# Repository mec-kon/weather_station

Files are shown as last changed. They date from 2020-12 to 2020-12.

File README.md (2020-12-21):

# weather station
A simple weather station hardware for recording temperature, humidity, pressure and airquality.
The measured data can be provided over WiFi by using an ESP8266.
This hardware is available as open source hardware and released under GPL-3.0 license.

## Description
This is a circuitboard based on an ESP8266 for reading and evaluating sensor data.
By using an ESP8266, it is possible to evaluate sensor data directly and make it available via MQTT, for example.
This makes it very easy to integrate the weather station into existing smart home systems such as OpenHAB, Home Assistant or ioBroker.
Furthermore, the ESP8266 has an efficient low power mode, which allows battery operation or operation on a solar cell.

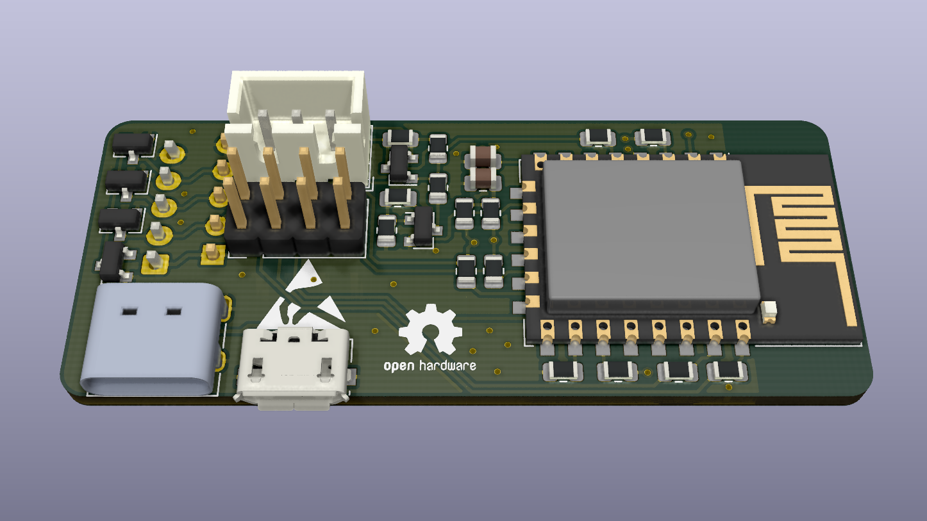
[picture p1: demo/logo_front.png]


## Connections

The board has six connection terminals.
Three different for the power supply, two for the connection of external sensors and one for programming the ESP8266. 
The power can be supplied via micro-usb, usb-c or via a JST-XH plug.
If the JST-XH connector is used, the capacity of a battery connected to the board can also be measured.

## Applicable sensors

For temperature measurement, either an LM75 and a BME680 or BME280 can be used.
If the air quality is to be measured as well, a BME680 needs to be used, otherwise a cheaper BME280 sensor is sufficient for temperature, air pressure and humidity.

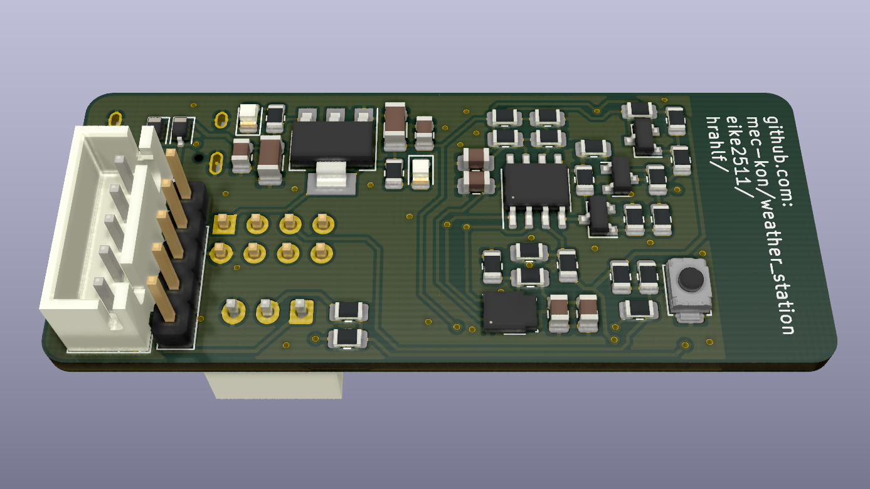
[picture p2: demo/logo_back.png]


## Low Power

To wake up the ESP8266 from low power mode, the reset pin must be connected to GPIO16. On the board presented here this connection has already been made.

## Additional external sensors

On the backside of the board a male pin header as well as a 5-pin JST-XH connector are located, to which further I2C devices or similar can be connected.

## Programming

The ESP8266 can be programmed with an FTDI adapter. All needed pins can be found on the pin header on the front side.
Example Software is provided here:

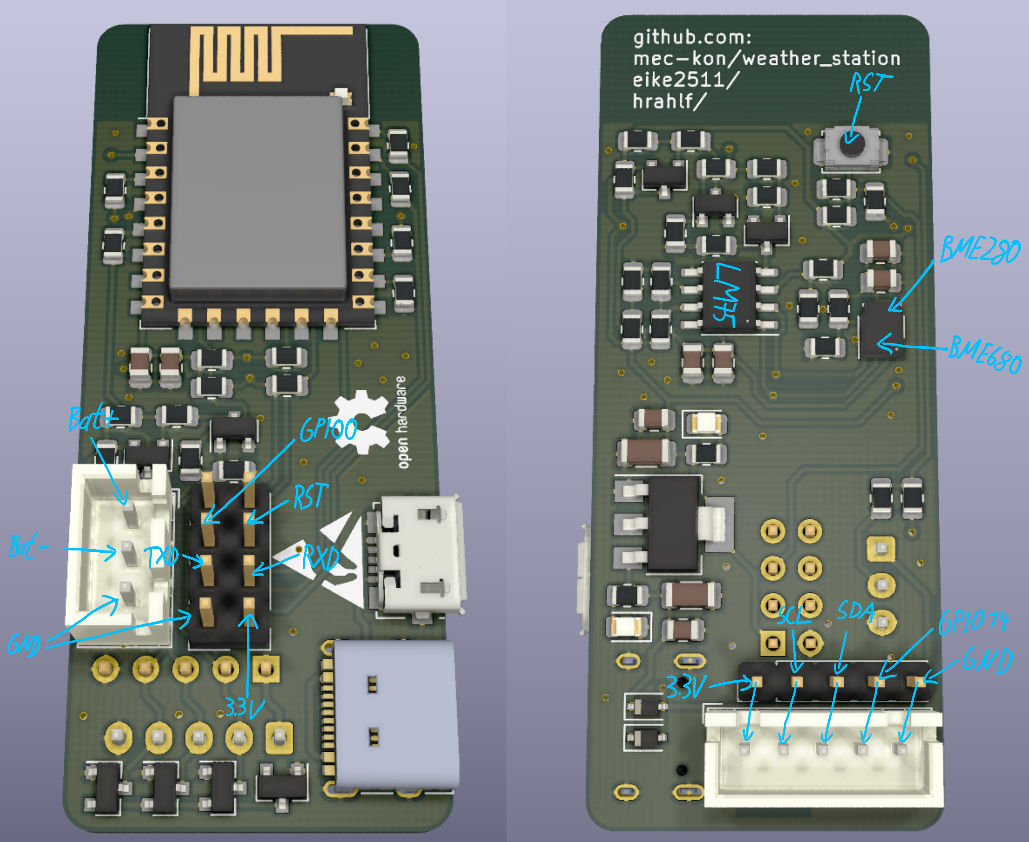
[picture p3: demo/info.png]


## Measuring the battery level

To measure the battery level, it is recommended to use a TP4056 battery charger. An additional device for charging the battery can be connected to it.
The upper pin of the JST-XH connector then corresponds to B+, the middle to B- and the lower to GND (B- and OUT- on TP4056).

## Dimensions and Schematic

24.13mmx57.8mm

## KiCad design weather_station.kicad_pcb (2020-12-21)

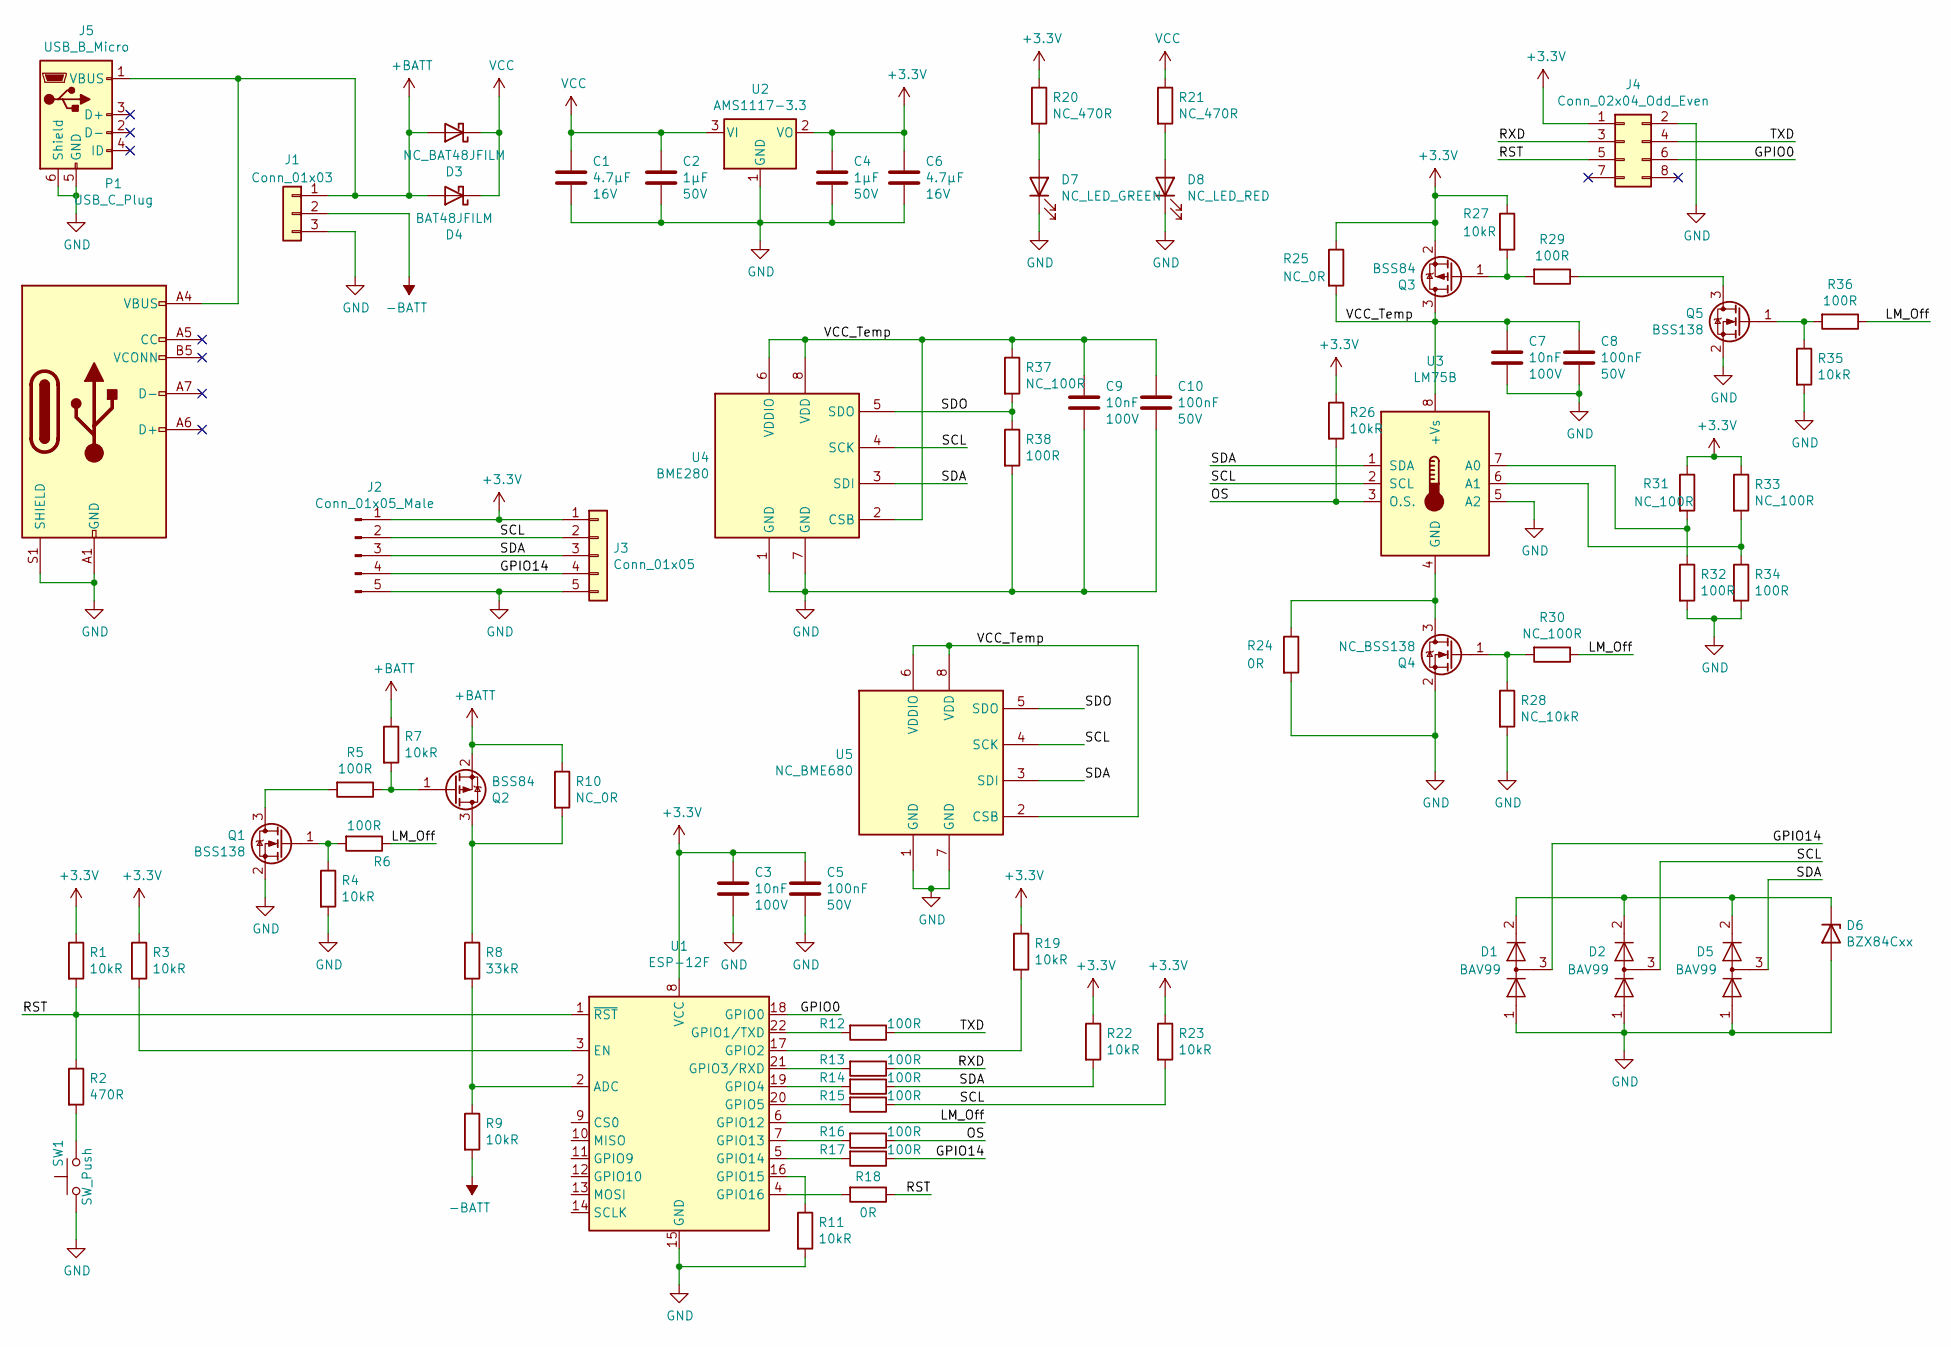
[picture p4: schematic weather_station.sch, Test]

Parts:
C1, C6: 4.7µF; C_1206_3216Metric
C2, C4: 1µF; C_0805_2012Metric
C3, C7, C9: 10nF; C_0805_2012Metric
C5, C8, C10: 100nF; C_0805_2012Metric
D1, D2, D5: BAV99; SOT-23
D3: NC_BAT48JFILM; D_SOD-323
D4: BAT48JFILM; D_SOD-323
D6: BZX84Cxx; D_SOT-23_ANK
D7: NC_LED_GREEN; LED_0805_2012Metric
D8: NC_LED_RED; LED_0805_2012Metric
J1: Conn_01x03; JST_XH_B3B-XH-A_1x03_P2.50mm_Vertical
J2: Conn_01x05_Male; PinHeader_1x05_P2.54mm_Vertical
J3: Conn_01x05; JST_XH_B5B-XH-A_1x05_P2.50mm_Vertical
J4: Conn_02x04_Odd_Even; PinHeader_2x04_P2.54mm_Vertical
J5: USB_B_Micro; USB_Micro-B_Molex_47346-0001
P1: USB_C_Plug; USB_C_Receptacle_XKB_U262-16XN-4BVC11
Q1, Q5: BSS138; SOT-23
Q2, Q3: BSS84; SOT-23
Q4: NC_BSS138; SOT-23
R1, R3, R4, R7, R9, R11, R19, R22, R23, R26, R27, R35: 10kR; R_0805_2012Metric
R2: 470R; R_0805_2012Metric
R5, R6, R12, R13, R14, R15, R16, R17, R29, R32, R34, R36, R38: 100R; R_0805_2012Metric
R8: 33kR; R_0805_2012Metric
R10, R25: NC_0R; R_0805_2012Metric
R18, R24: 0R; R_0805_2012Metric
R20, R21: NC_470R; R_0805_2012Metric
R28: NC_10kR; R_0805_2012Metric
R30, R31, R33, R37: NC_100R; R_0805_2012Metric
SW1: SW_Push; SW_Push_SPST_4x3x2
U1: ESP-12F; ESP-12E
U2: AMS1117-3.3; SOT-223-3_TabPin2
U3: LM75B; SSOP-8_3.9x5.05mm_P1.27mm
U4: BME280; Bosch_LGA-8_2.5x2.5mm_P0.65mm_ClockwisePinNumbering
U5: NC_BME680; Bosch_LGA-8_3x3mm_P0.8mm_ClockwisePinNumbering

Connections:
+3V3: C3.1, C4.1, C5.1, C6.1, J2.1, J3.1, J4.1, Q3.2 (S), R1.1, R3.1, R19.1, R20.1, R22.1, R23.1, R25.1, R26.1, R27.1, R31.1, R33.1, U1.8 (VCC), U2.2 (VO)
+BATT: D3.2 (A), D4.2 (A), J1.1, J5.1 (VBUS), P1.A4 (VBUS), P1.A9 (VBUS), P1.B4 (VBUS), P1.B9 (VBUS), Q2.2 (S), R7.1, R10.1
-BATT: J1.2, R9.2
/GPIO0: J4.6, U1.18 (GPIO0)
/GPIO14: D1.3 (K), J2.4, J3.4, R17.1
/LM_Off: R6.1, R30.1, R36.1, U1.6 (GPIO12)
/OS: R16.1, R26.2, U3.3 (O.S.)
/RST: J4.5, R1.2, R2.1, R18.1, U1.1 (~RST)
/RXD: J4.3, R13.1
/SCL: D2.3 (K), J2.2, J3.2, R15.1, R23.2, U3.2 (SCL), U4.4 (SCK), U5.4 (SCK)
/SDA: D5.3 (K), J2.3, J3.3, R14.1, R22.2, U3.1 (SDA), U4.3 (SDI), U5.3 (SDI)
/SDO: R37.2, R38.1, U4.5 (SDO), U5.5 (SDO)
/TXD: J4.4, R12.1
/VCC_Temp: C7.1, C8.1, C9.1, C10.1, Q3.3 (D), R25.2, R37.1, U3.8 (+Vs), U4.2 (CSB), U4.6 (VDDIO), U4.8 (VDD), U5.2 (CSB), U5.6 (VDDIO), U5.8 (VDD)
GND: C1.2, C2.2, C3.2, C4.2, C5.2, C6.2, C7.2, C8.2, C9.2, C10.2, D1.1 (K), D2.1 (K), D5.1 (K), D6.2 (A), D7.1 (K), D8.1 (K), J1.3, J2.5, J3.5, J4.2, J5.5 (GND), J5.6 (Shield), P1.A1 (GND), P1.A12 (GND), P1.B1 (GND), P1.B12 (GND), P1.S1 (SHIELD), Q1.2 (S), Q4.2 (S), Q5.2 (S), R4.2, R11.2, R24.2, R28.2, R32.2, R34.2, R35.2, R38.2, SW1.1, U1.15 (GND), U2.1 (GND), U3.5 (A2), U4.1 (GND), U4.7 (GND), U5.1 (GND), U5.7 (GND)
unnamed: D1.2 (A), D2.2 (A), D5.2 (A), D6.1 (K)
unnamed: D7.2 (A), R20.2
unnamed: D8.2 (A), R21.2
unnamed: Q1.1 (G), R4.1, R6.2
unnamed: Q1.3 (D), R5.2
unnamed: Q2.1 (G), R5.1, R7.2
unnamed: Q2.3 (D), R8.1, R10.2
unnamed: Q3.1 (G), R27.2, R29.2
unnamed: Q4.1 (G), R28.1, R30.2
unnamed: Q4.3 (D), R24.1, U3.4 (GND)
unnamed: Q5.1 (G), R35.1, R36.2
unnamed: Q5.3 (D), R29.1
unnamed: R2.2, SW1.2
unnamed: R3.2, U1.3 (EN)
unnamed: R8.2, R9.1, U1.2 (ADC)
unnamed: R11.1, U1.16 (GPIO15)
unnamed: R12.2, U1.22 (GPIO1/TXD)
unnamed: R13.2, U1.21 (GPIO3/RXD)
unnamed: R14.2, U1.19 (GPIO4)
unnamed: R15.2, U1.20 (GPIO5)
unnamed: R16.2, U1.7 (GPIO13)
unnamed: R17.2, U1.5 (GPIO14)
unnamed: R18.2, U1.4 (GPIO16)
unnamed: R19.2, U1.17 (GPIO2)
unnamed: R31.2, R32.1, U3.7 (A0)
unnamed: R33.2, R34.1, U3.6 (A1)
VCC: C1.1, C2.1, D3.1 (K), D4.1 (K), R21.1, U2.3 (VI)

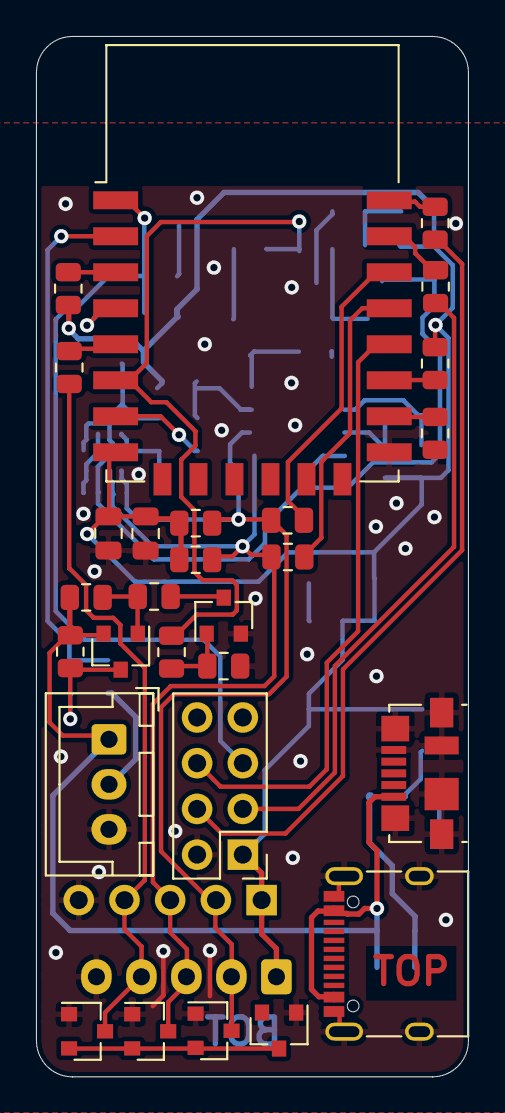
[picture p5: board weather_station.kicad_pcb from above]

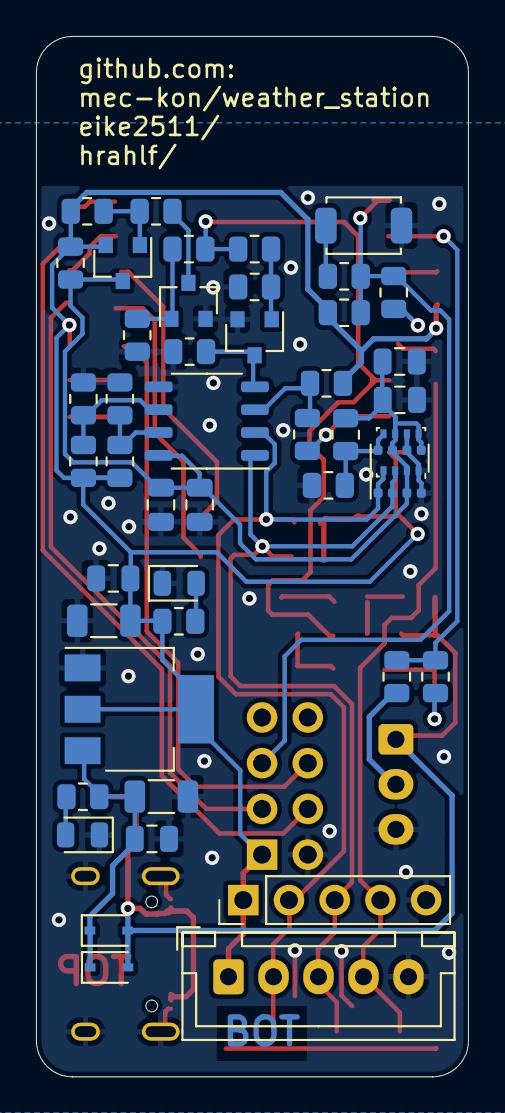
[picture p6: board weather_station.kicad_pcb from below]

Board: 2 copper layers, 24.0 x 57.8 mm, 73 parts (45 on the bottom side), 42 nets.

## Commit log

2020-12-10 edit silkscreen
    [weather_station.kicad_pcb]
2020-12-10 added gerber and drill files
    [weather_station-B_Cu.gbr, weather_station-B_Mask.gbr, weather_station-B_Paste.gbr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]
2020-12-15 Add active html bom
2020-12-19 changed 3d model path
    [weather_station.kicad_pcb]
2020-12-21 Edit NC Components and update footprints
    [weather_station.kicad_pcb, weather_station.sch]
